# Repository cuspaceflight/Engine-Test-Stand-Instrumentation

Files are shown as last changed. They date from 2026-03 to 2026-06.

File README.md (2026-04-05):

# Cambridge University Space Flight Engine Test Stand

This repo contains documents for CUSF engine test stand. The electronics are split across 2 circuit boards:

**Servo + Solenoid Board**  Drives 2 solenoid valves (MPQ6610 half-bridge ICs) and up to 4 servos
**Instrumentation Board** Reads pressure transducers, thermocouples, and a load cell for thrust measurement

A laptop running ground-station software sends commands to the ESP32 on the servo board, and polls the Instrumentation Board to read sensor data

## Board Details

### Servo + Solenoid Board

This board contains the circuits for driving the servos and solenoids. Uses an ESP32 microcontroller (ESP32 S3 DevKit C1). The microcontroller is alos responsible for: 
 - Communication with laptop
 - Driving servos and solenoids
 - Inputs raw data from sensors and sends to laptop

#### Solenoid Section

Each of the solenoid channels uses an **MPS MPQ6610** half-bridge power driver. 

#### Servo Section

4 servos (FeeTech 180 Degrees Digital Servo 7.4V 35kg/cm FT5330M)
 - PWM signal from ESP32

### Instrumentation Board

- Load cell
- 8 Pressure sensors
- 4 thermocouples

## Repository Structure

```
cusf-engine_test_stand/
│
├── hardware/
│   ├── master-board/
│   │   ├── kicad/              # Schematic + PCB project
│   │
│   ├── servo-solenoid-board/
│   │   ├── kicad/
│   │
│   ├── instrumentation-board/
│   │   ├── kicad/
│   │
│   ├── Datasheets
│   │   ├── MPQ6610.pdf
│   │
│
├── Software/
│   ├── servo/
│   ├── solenoid/
│   ├── instrumentation/
│   ├──Laptop software (GUI + logging)
│
└── README.md

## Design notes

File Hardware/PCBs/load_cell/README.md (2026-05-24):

# CUSF Load Cell Interface Board

## Overview

Signal conditioning board for the PW16A load cell, providing excitation voltage, instrumentation amplification, low-pass filtering, and buffered voltage references for ADC reading.

---

## Connector

| Designator | Description |
|---|---|
| J1 | RS Pro M12 Connector Female, 8W-8C, 5m, PVC, Shield |

---

## Load Cell

| Parameter | Value |
|---|---|
| Model | PW16A |
| Sensitivity | 2 mV/V |
| Excitation Voltage | 10 V |
| Full-scale Output | 20 mV (0.02 V) |

---

## Power Section

### Voltage Regulation & References

| Designator | Part | Description | Package |
|---|---|---|---|
| U4 | L78L05 | 5V Positive Linear Regulator, 100mA, 30V Max Input | SOIC-8 |
| U2 | REF5010AD | 10V Precision Voltage Reference, 0.1% Accuracy, 10mA, Low Noise | SOIC-8 |
| U5 | REF3033 | 3.3V CMOS Voltage Reference, 50 ppm/°C Max, 50 µA | SOT-23 |

### Op-Amp Buffers

| Designator | Part | Description | Package | Purpose |
|---|---|---|---|---|
| U3 | OPA197xD | 36V Precision, Rail-to-Rail I/O, Low Offset Voltage Op-Amp | SOIC-8 | 10V reference buffer |
| U6 | OPA333xxD | 1.8V microPower, CMOS Zero-Drift Op-Amp | SOIC-8 | 3.3V reference buffer |

### Resistors

| Designator | Value | Package |
|---|---|---|
| R2 | 1 Ω | 0805 |
| R3 | 16.2 kΩ | 0805 |
| R4 | 1.8 kΩ | 0805 |

### Capacitors

| Designator | Value | Package |
|---|---|---|
| C3 | 100 nF | 0805 |
| C4 | 100 nF | 0805 |
| C5 | 100 nF | 0805 |
| C6 | 100 nF | 0805 |
| C7 | 10 µF | 0805 |
| C8 | 10 µF | 0805 |
| C9 | 10 µF | 0805 |
| C10 | 1 µF | 0805 |
| C11 | 100 nF | 0805 |
| C12 | 1 µF | 0805 |
| C13 | 100 nF | 0805 |

### Outputs

| Signal | Source | Description |
|---|---|---|
| VOUT_10V | REF5010AD + OPA197xD buffer | 10V excitation for load cell |
| VREF_0.33V | REF3033 + OPA333xxD buffer | 0.33V reference for ADC |

---

## Analogue Signal Section

### Instrumentation Amplifier

| Designator | Part | Description | Package |
|---|---|---|---|
| U1 | AD8422 | Single High Performance, Low Power, Rail-to-Rail Precision In-Amp | SOIC-8 |

| Parameter | Value |
|---|---|
| Gain (G) | 150 |
| Gain Resistor (RG) | 133 Ω |
| Formula | RG = 19.8 kΩ / (G − 1) |
| Supply Voltage | +15V (single-supply) |
| Output to ESP | 3.0 V |

### Gain Resistor

| Designator | Value | Package |
|---|---|---|
| RG | 133 Ω | 0805 |

### Low-Pass Filter

| Designator | Value | Package | Notes |
|---|---|---|---|
| R1 | 5.36 kΩ | 0805 | Series resistor |
| C1 | 10 nF | 0805 | Shunt capacitor |

| Parameter | Value |
|---|---|
| Cut-off Frequency | 2.97 kHz |
| Topology | RC low-pass filter |

### Decoupling Capacitor

| Designator | Value | Package |
|---|---|---|
| C2 | 0.1 µF | 0805 |

### Signals

| Signal | Direction | Description |
|---|---|---|
| LC_SIG+ | Input | Load cell differential signal (+) |
| LC_SIG- | Input | Load cell differential signal (−) |
| +15V_Analog | Input | 15V supply for AD8422 |
| V_REF | Input | 0.33V reference for AD8422 output offset |
| ADC_OUT_TO_MIC | Output | Filtered, amplified signal to microcontroller ADC |
| AGND | — | Analogue ground |

---

## Inter-Sheet Connections

| Main Sheet Label | Power Sheet | Analogue Signal Sheet | J1 (M12 Connector) |
|---|---|---|---|
| VIN_15V | Input | — | — |
| VOUT_10V | ← Output | — | — |
| VREF_0.33V | ← Output | → V_REF | — |
| +10V_EXC | — | — | Pins 1, 8 |
| LC_SIG+ | — | ← Input | Pin (signal) |
| LC_SIG- | — | ← Input | Pin (signal) |
| AGND | ✓ | ✓ | Ground pins |
| ADC_OUT_TO_MIC | — | → Output | — |

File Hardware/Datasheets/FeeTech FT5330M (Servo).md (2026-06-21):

# Servo Motor Specifications

### Environmental & Physical Specifications
* **Storage Temperature Range:** -30 ~ 80 °C
* **Operating Temperature Range:** -20 ~ 60 °C
* **Weight:** 67 ± 1 g
* **Case Material:** PA + Aluminum

### Mechanical Specifications
* **Gear Type:** Steel
* **Limit Angle:** No limit
* **Bearing Type:** Ball bearings
* **Horn Gear Spline:** 25T / 5.9 mm
* **Horn Type:** Plastic, POM

### Electrical Specifications
* **Motor Type:** Core Motor
* **Operating Voltage Range:** 6.0 V - 7.4 V
* **Idle Current (at stopped):** 6 mA @ 7.4 V
* **Running Current (at no load):** 180 mA @ 7.4 V
* **Stall Current:** 3.9 A @ 7.4 V

### Performance Specifications
* **No-load Speed:** 0.192 sec / 60° @ 7.4 V
* **Peak Stall Torque:** 35.5 kg·cm @ 7.4 V
* **Rated Torque:** 11.8 kg·cm @ 7.4 V

### Control & Signal Specifications
* **Command Signal:** Pulse Width Modulation (PWM)
* **Amplifier Type:** Digital comparator
* **Pulse Width Range:** 500 ~ 2500 μsec
* **Stop Position:** 1500 μsec
* **Running Degree:** 220° Continuous Rotation
* **Dead Band Width:** ≤ 4 μsec
* **Rotating Direction:** Counterclockwise (1500 - 2000 μsec)

### Pin Definition
* **Pin 1:** Signal
* **Pin 2:** Vcc
* **Pin 3:** GND

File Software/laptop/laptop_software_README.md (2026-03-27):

# Ground Station GUI — Technical Documentation

## What this software does

This is the laptop application for the CUSF static fire test stand. It connects to the ESP32-S3 microcontroller on the actuation board over a USB cable and lets the operator control valves and monitor sensors during an engine test firing.

The software is three Python files totalling about 500 lines. Each file has one job:

| File | Job | Analogy |
|---|-----|---|
| `protocol.py` | Defines the language the GUI and ESP32 speak | A dictionary / phrasebook |
| `serial_comms.py` | Manages the USB cable connection | A telephone line |
| `main.py` | The window you see and click on | The control room |

---

## How it connects to the hardware

```
 ┌─────────────┐    USB-C cable    ┌───────────────────────────┐
 │   LAPTOP    │◄─────────────────►│   ACTUATION BOARD         │
 │             │   (virtual serial │                           │
 │  main.py    │    port, 115200   │   ESP32-S3-DevKitC-1     │
 │  (this GUI) │    baud)          │     │                     │
 │             │                   │     ├── GPIO → MPQ6610 #1 ──► Solenoid 1
 └─────────────┘                   │     ├── GPIO → MPQ6610 #2 ──► Solenoid 2
                                   │     ├── PWM  → Servo 1 (FT5330M)
                                   │     ├── PWM  → Servo 2 (FT5330M)
                                   │     ├── PWM  → Servo 3 (FT5330M)
                                   │     ├── PWM  → Servo 4 (FT5330M)
                                   │     └── Bus  → Instrumentation Board
                                   └───────────────────────────┘
```

The ESP32-S3 has **native USB** built into the chip (on GPIO19 and GPIO20). When you plug a USB-C cable into the DevKitC-1, the laptop sees it as a virtual serial port — `COM3` on Windows or `/dev/ttyACM0` on Linux. No special driver is needed.

Serial communication is just sending text back and forth, one line at a time, at 115200 bits per second. It is the same protocol the Arduino Serial Monitor uses.

---

## File 1: protocol.py

### Purpose

This file is a contract between the GUI and the ESP32 firmware. It defines exactly what strings are sent in each direction and provides Python classes to construct and parse them.

Your teammate writing the ESP32 firmware needs to agree on this file. If both sides follow the same protocol, they will work together even though they are written independently.

### How the protocol works

Every message is a line of ASCII text ending with a newline character (`\n`). We use text rather than binary because:

1. You can type commands into any serial terminal for debugging
2. You can read the log files with a text editor
3. Parsing is simple string splitting

### Commands (GUI → ESP32)

When you click a button in the GUI, it creates a Command object and sends it over serial. Here is the complete chain for turning on solenoid 1:

```
User clicks "SOL 1" button
        │
        ▼
GUI creates: SolenoidCommand(channel=1, on=True)
        │
        ▼
SolenoidCommand.to_str() returns: "SOL1:ON\n"
        │
        ▼
SolenoidCommand.to_bytes() encodes to: b"SOL1:ON\n"
        │
        ▼
pyserial sends these bytes over USB
        │
        ▼
ESP32 receives "SOL1:ON\n", sets MPQ6610 #1 EN=HIGH, IN=HIGH
        │
        ▼
MPQ6610 high-side MOSFET turns on → 24V flows through solenoid
        │
        ▼
Solenoid energises → valve opens
```

### Messages (ESP32 → GUI)

The ESP32 periodically sends sensor readings and fault status without being asked. The `parse_response()` function converts each line into a typed Python object:

```
ESP32 sends: "FAULT:1:0\n"
        │
        ▼
parse_response("FAULT:1:0") splits on ":"
        │
        ▼
Returns: FaultMessage(channel=1, ok=False)
        │
        ▼
GUI checks isinstance(msg, FaultMessage)
        │
        ▼
Updates the nFAULT indicator for channel 1 to red
```

### The class hierarchy

```
Command (base class — "something we send")
├── SolenoidCommand    channel, on        → "SOL1:ON\n"
├── ServoCommand       channel, pulse_us  → "SRV2:1500\n"
└── StatusCommand      (no data)          → "STATUS\n"

Message (base class — "something we receive")
├── FaultMessage       channel, ok        ← "FAULT:1:0"
├── SensorMessage      name, value        ← "SENSOR:PRESS1:3.45"
├── AckMessage         (no data)          ← "OK"
├── ErrorMessage       message            ← "ERROR:Invalid command"
├── StatusMessage      raw                ← "STATUS:SOL1:ON:..."
└── UnknownMessage     raw                ← anything else
```

### What @dataclass does

The `@dataclass` decorator is a shortcut. It automatically generates the `__init__` method and a readable `__repr__`. These two are equivalent:

```python
# Without @dataclass (verbose)
class FaultMessage(Message):
    def __init__(self, channel: int, ok: bool):
        self.channel = channel
        self.ok = ok
    def __repr__(self):
        return f"FaultMessage(channel={self.channel}, ok={self.ok})"

# With @dataclass (compact — Python generates the above for you)
@dataclass
class FaultMessage(Message):
    channel: int
    ok: bool
```

### What `__post_init__` does (in ServoCommand)

`@dataclass` generates `__init__` for you, so you cannot write your own. But sometimes you need to run extra logic after the object is created (like clamping the servo pulse range to 500–2500). `__post_init__` is called automatically right after `__init__` finishes:

```python
cmd = ServoCommand(channel=1, pulse_us=9999)
# 1. @dataclass __init__ runs:  self.channel=1, self.pulse_us=9999
# 2. __post_init__ runs:        self.pulse_us = max(500, min(2500, 9999)) → 2500
# Result: cmd.pulse_us == 2500
```

---

## File 2: serial_comms.py

### Purpose

Manages the USB serial connection to the ESP32. Handles port discovery, connecting, disconnecting, sending commands, and reading incoming data on a background thread.

### Why a background thread?

Serial reading is **blocking** — `ser.readline()` waits until a complete line arrives. If you did this on the main thread (the one running the GUI), the entire window would freeze:

```
Without background thread:
    User clicks button → GUI tries to read serial → waits...
    → waits... → waits... → meanwhile GUI is frozen, user
    can't click anything, window says "Not Responding"
```

With a background thread, reading happens independently:

```
Main thread:              Background thread:
    GUI draws widgets         Checks for serial data
    User clicks buttons       Reads a line
    Sliders move              Parses it
    Labels update             Calls the callback
         ▲                          │
         └──── self.after() ────────┘
              (safely passes data between threads)
```

### The callback pattern explained

The serial module doesn't know anything about the GUI. It doesn't import `main.py`. Instead, the GUI gives serial_comms a function to call when data arrives. This is called the **callback pattern**.

Here is the simplest possible example of the pattern:

```python
# === The serial module's perspective ===
class SerialConnection:
    def __init__(self):
        self._on_receive = None       # No callback yet

    def set_callback(self, func):
        self._on_receive = func       # Store the function

    def _read_loop(self):
        data = "FAULT:1:0"            # Pretend we read this
        msg = parse_response(data)    # Turn it into a FaultMessage
        self._on_receive(msg)         # Call whatever function was stored

# === The GUI's perspective ===
class MyGUI:
    def __init__(self):
        self.serial = SerialConnection()

        # "When you get data, call my handle_it method"
        self.serial.set_callback(self.handle_it)

    def handle_it(self, msg):
        print(f"GUI got: {msg}")
```

When `_read_loop` runs `self._on_receive(msg)`, it is calling `self.handle_it(msg)` on the GUI — because that is the function that was stored by `set_callback`.

Think of it like a restaurant:
1. You give the waiter your phone number (set_callback)
2. The waiter writes it down (_on_receive = func)
3. When your table is ready, the waiter calls you (_on_receive(msg))
4. You pick up the phone and act on it (handle_it runs)

### Thread safety and self.after()

There is one complication: the callback runs on the **background thread**, but GUI widgets (buttons, labels, etc.) can only be updated from the **main thread**. If you try to change a label's text from the background thread, the application crashes.

The solution is `self.after(0, function, args)`, which means: "schedule this function to run on the main thread as soon as possible."

```python
def on_serial_receive(self, msg):
    # This runs on the BACKGROUND thread (called by _read_loop)
    # Do NOT touch any GUI widgets here!

    # Instead, schedule _handle_message to run on the main thread:
    self.after(0, self._handle_message, msg)

def _handle_message(self, msg):
    # This runs on the MAIN thread (scheduled by self.after)
    # Safe to update GUI widgets here:
    self.fault_labels[1].configure(text="● FAULT!", text_color="red")
```

### The read loop in detail

```python
def _read_loop(self):
    while self._running:                    # Loop until disconnect() sets this False
        if self.ser.in_waiting:             # Are there bytes in the USB buffer?
            raw = self.ser.readline()       #   YES: read one line (blocks until \n)
            text = raw.decode("utf-8")      #   Convert bytes to string
            msg = parse_response(text)      #   "FAULT:1:0" → FaultMessage(1, False)
            self._on_receive(msg)           #   Call the GUI's callback
        else:
            time.sleep(0.01)                #   NO: wait 10ms, check again
```

The `in_waiting` check is important. Without it, `readline()` would block for up to 100ms (the timeout we set) every iteration, even when there is no data. By checking first, we only call readline when we know data is there — this keeps the loop responsive.

---

## File 3: main.py

### Purpose

The GUI window — everything the operator sees and interacts with. Built with `customtkinter`, which is a modern-looking wrapper around Python's built-in `tkinter` GUI library.

### Window layout

```
┌──────────────────────────────────────────────────┐
│  [Port: COM3 ▼]  [Refresh]  [Connect]  ● Green  │  ← Connection bar
├────────────────────────┬─────────────────────────┤
│  Solenoids             │  Sensors                │
│  ┌─────────────┬─────┐ │  Pressure 1:  3.4 bar   │
│  │ SOL 1: OFF  │ ● OK│ │  Pressure 2:  2.1 bar   │
│  │ SOL 2: OFF  │ ● OK│ │  Temperature: 25.3 °C   │
│  └─────────────┴─────┘ │  Thrust:      142.7 N   │
│                         │                         │
│  Servos                 │  Log                    │
│  [All Closed] [Centre]  │  [09:41:23] Connected   │
│  Servo 1: ───●─── 1500 │  [09:41:24] SOL 1 → ON  │
│  Servo 2: ───●─── 1500 │  [09:41:25] SENSOR ...  │
│  Servo 3: ───●─── 1500 │  [09:41:25] FAULT on 1! │
│  Servo 4: ───●─── 1500 │  [09:41:26] SENSOR ...  │
└────────────────────────┴─────────────────────────┘
```

### How each GUI element maps to hardware

**Solenoid buttons → MPQ6610 → Solenoid valves**

When you click "SOL 1", the GUI sends `SOL1:ON\n` over USB. The ESP32 firmware receives this, sets GPIO4=HIGH (EN) and GPIO5=HIGH (IN). Inside the MPQ6610, this turns on the high-side MOSFET, connecting the solenoid coil to the 24V supply. Current flows through the coil, creating a magnetic field that pulls the plunger and opens the valve.

When you click again (OFF), the GUI sends `SOL1:OFF\n`. The ESP32 sets GPIO4=LOW (EN). The MPQ6610 turns off both MOSFETs (Hi-Z state). Current stops flowing, the solenoid's spring pushes the plunger back, and the valve closes.

**nFAULT indicators → MPQ6610 nFAULT pin → ESP32 GPIO**

The MPQ6610 has a built-in fault detection pin (nFAULT). It is normally HIGH (pulled up by a 10kΩ resistor to 3.3V). If the MPQ6610 detects a problem — solenoid drawing too much current (>3A), chip overheating (>165°C), solenoid disconnected, or supply voltage too low (<4.1V) — it pulls nFAULT LOW.

The ESP32 reads this pin (GPIO8 for channel 1, GPIO9 for channel 2) and sends `FAULT:1:0\n` or `FAULT:1:1\n` to the GUI. The GUI updates the indicator dot: green for OK, red for FAULT.

**Servo sliders → ESP32 LEDC PWM → FT5330M servos → Ball valves**

When you drag a slider, the GUI sends (for example) `SRV1:1800\n`. The ESP32 firmware updates its LEDC peripheral to output a 50Hz PWM signal with an 1800µs pulse width on the corresponding GPIO pin (GPIO10–13). The FT5330M servo's internal controller reads this pulse and moves the output shaft to the corresponding angle. The servo horn is mechanically linked to a ball valve, rotating it to control flow.

The FT5330M accepts 500–2500µs pulses (0–180°). The slider is clamped to this range.

**Sensor readings → Instrumentation board → ESP32 → GUI**

The ESP32 periodically polls the instrumentation board (your teammate's board) over the inter-board bus. It reads pressure transducers, thermocouples, and the load cell, then sends `SENSOR:PRESS1:3.45\n` to the GUI. The GUI updates the number on screen. These readings are also logged to a CSV file.

The solenoid control logic on the ESP32 uses these sensor readings to make decisions — for example, opening the fuel valve when tank pressure reaches a target value.

### The main thread vs background thread

This is the most important architectural concept in the code. Python GUI applications (tkinter, Qt, etc.) have a strict rule: **only the main thread can touch GUI widgets**. If a background thread tries to change a label's text, the application crashes or behaves unpredictably.

But we need a background thread to read serial data continuously without freezing the GUI. The solution:

```
MAIN THREAD                         BACKGROUND THREAD
(runs the GUI)                      (reads serial data)
     │                                    │
     │  app.mainloop()                    │  _read_loop()
     │  ├── draws widgets                 │  ├── ser.readline()
     │  ├── handles button clicks         │  ├── parse_response()
     │  ├── runs self.after() tasks ◄─────│──├── self._on_receive(msg)
     │  │         │                       │  │     calls on_serial_receive()
     │  │         ▼                       │  │     which calls self.after()
     │  │   _handle_message(msg)          │  │
     │  │   ├── update fault label        │  └── sleep, loop again
     │  │   ├── update sensor value       │
     │  │   └── write to log              │
     │  └── loop                          │
```

`self.after(0, func, args)` is the bridge: it says "next time the main thread's event loop checks, please run this function." It is safe because the function actually executes on the main thread — the background thread only schedules it.

### Logging

Every event is logged to two places:

1. **GUI log panel** — visible on screen, scrolls automatically, timestamped
2. **CSV file** — in the `logs/` folder, named by date/time, can be opened in Excel or Python for post-test analysis

The CSV format is: `timestamp,type,data`

```csv
2026-03-27T14:23:01.123,SENSOR PRESS1: 3.45
2026-03-27T14:23:01.124,SENSOR TEMP1: 25.3
2026-03-27T14:23:01.125,FAULT on solenoid 1!
2026-03-27T14:23:02.001,SOL 1 → OFF
```

---

## How to test without the ESP32

The `add_mock_data()` function at the bottom of `main.py` simulates the ESP32 sending data. Uncomment it in `__main__`:

```python
if __name__ == "__main__":
    app = TestStandGUI()
    add_mock_data(app)      # ← uncomment this line
    app.mainloop()
```

This calls `_handle_message()` directly every 200ms with fake sensor readings and occasional fault events. The GUI behaves exactly as it would with a real ESP32, except no USB cable is needed. Use this to develop and demo the GUI before the hardware is ready.

---

## Dependencies

```bash
pip install pyserial customtkinter matplotlib
```

| Library | Version | What it does |
|---|---|---|
| `pyserial` | 3.5+ | Talks to the ESP32 over the USB virtual serial port |
| `customtkinter` | 5.0+ | Modern-looking GUI widgets (buttons, sliders, labels) |
| `matplotlib` | 3.7+ | For live plots (to be added in a future version) |
| `tkinter` | (built-in) | The underlying GUI framework. Ships with Python. |
| `threading` | (built-in) | Background thread for serial reading |
| `dataclasses` | (built-in) | The `@dataclass` decorator for protocol classes |

---

## File structure

```
ground-station/
├── main.py              # GUI window — run this
├── serial_comms.py      # USB serial connection handler
├── protocol.py          # Protocol definition (commands + messages)
├── logs/                # Auto-created, contains CSV log files
│   └── log_20260327_142301.csv
└── README.md            # This file
```

---

## Glossary

| Term | Meaning |
|---|---|
| **Baud rate** | Communication speed in bits per second. 115200 is standard for ESP32. Both sides must agree on the same rate. |
| **Callback** | A function you pass to another module for it to call later. Like leaving your phone number at a restaurant. |
| **Daemon thread** | A background thread that automatically terminates when the main program exits. Set with `daemon=True`. |
| **LEDC** | LED Control — the ESP32's hardware PWM peripheral. Despite the name, it is used for servo control too. Generates precise pulse timing without CPU involvement. |
| **Main thread** | The thread that runs the GUI event loop (`mainloop()`). Only this thread may update widget properties. |
| **MPQ6610** | The half-bridge solenoid driver IC. Receives EN and IN signals from ESP32 GPIOs. Drives 24V through the solenoid coil. Reports faults on the nFAULT pin. |
| **nFAULT** | Active-low fault indicator on the MPQ6610. "n" prefix means the signal is active when LOW. Pulled HIGH by a 10kΩ resistor when everything is fine. |
| **PWM** | Pulse Width Modulation. A digital signal that switches between high and low at a fixed frequency. The ratio of high time to total period (the duty cycle) encodes information — for servos, it encodes the desired angle. |
| **pyserial** | Python library for serial port communication. Provides the `serial.Serial` class that reads/writes bytes over USB. |
| **self.after()** | A tkinter method that schedules a function to run on the main thread after a delay (0ms = as soon as possible). Used to safely pass data from a background thread to the GUI. |
| **Virtual serial port** | When the ESP32-S3's native USB is connected, the operating system creates a software serial port (COM3, /dev/ttyACM0) that programs can read/write as if it were a physical RS-232 port. |

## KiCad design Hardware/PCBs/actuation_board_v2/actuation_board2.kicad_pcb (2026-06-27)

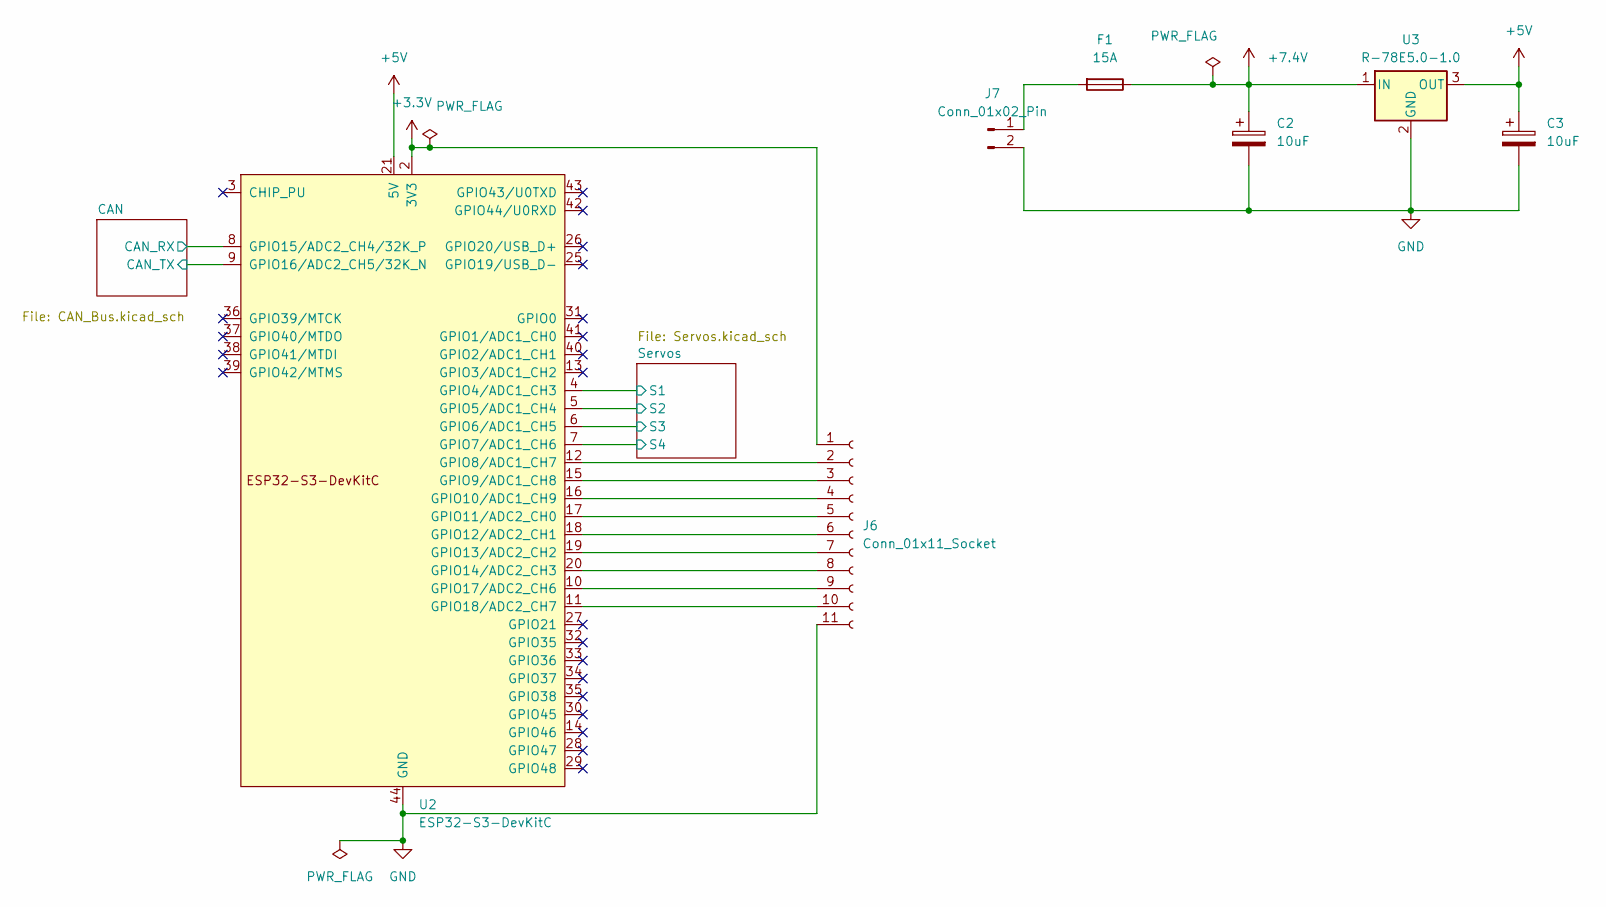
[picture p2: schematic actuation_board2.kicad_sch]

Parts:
C2, C3: 10uF; C_0603_1608Metric_Pad1.08x0.95mm_HandSolder
F1: 15A; Fuse_1206_3216Metric_Pad1.42x1.75mm_HandSolder
J6: Conn_01x11_Socket; PinSocket_1x11_P2.54mm_Vertical
J7: Conn_01x02_Pin; AMASS_XT60PW-M_1x02_P7.20mm_Horizontal
U2: ESP32-S3-DevKitC
U3: R-78E5.0-1.0; Converter_DCDC_RECOM_R-78E-0.5_THT

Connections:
+3.3V: J6.1, U2.1 (3V3), U2.2 (3V3); also elsewhere on the board
+5V: C3.1, U2.21 (5V), U3.3 (OUT)
+7.4V: C2.1, F1.1, U3.1 (IN); also elsewhere on the board
/CAN/CAN_RX: U2.8 (GPIO15/ADC2_CH4/32K_P); also elsewhere on the board
/CAN/CAN_TX: U2.9 (GPIO16/ADC2_CH5/32K_N); also elsewhere on the board
/Servos/S1: U2.4 (GPIO4/ADC1_CH3); also elsewhere on the board
/Servos/S2: U2.5 (GPIO5/ADC1_CH4); also elsewhere on the board
/Servos/S3: U2.6 (GPIO6/ADC1_CH5); also elsewhere on the board
/Servos/S4: U2.7 (GPIO7/ADC1_CH6); also elsewhere on the board
GND: C2.2, C3.2, J6.11, J7.2, U2.22 (GND), U2.23 (GND), U2.24 (GND), U2.44 (GND), U3.2 (GND); also elsewhere on the board
unnamed: J6.2, U2.12 (GPIO8/ADC1_CH7)
unnamed: J6.3, U2.15 (GPIO9/ADC1_CH8)
unnamed: J6.4, U2.16 (GPIO10/ADC1_CH9)
unnamed: J6.5, U2.17 (GPIO11/ADC2_CH0)
unnamed: J6.6, U2.18 (GPIO12/ADC2_CH1)
unnamed: J6.7, U2.19 (GPIO13/ADC2_CH2)
unnamed: J6.8, U2.20 (GPIO14/ADC2_CH3)
unnamed: J6.9, U2.10 (GPIO17/ADC2_CH6)
unnamed: J6.10, U2.11 (GPIO18/ADC2_CH7)
unnamed: F1.2, J7.1

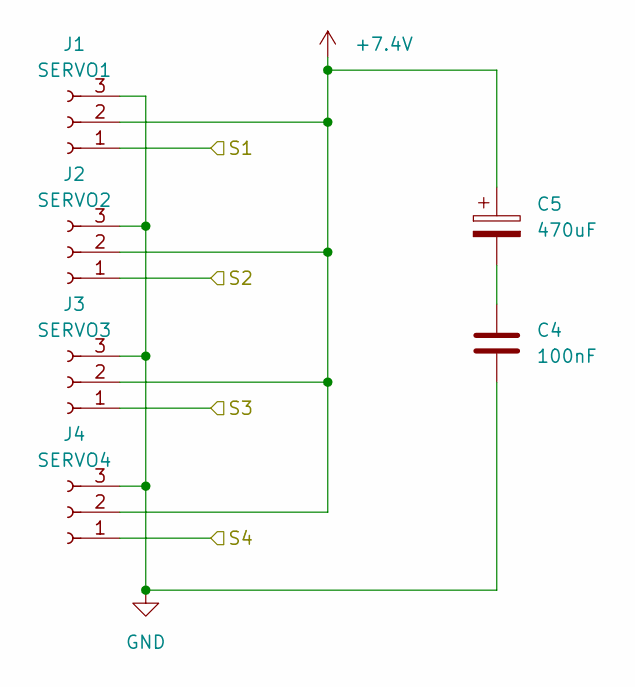
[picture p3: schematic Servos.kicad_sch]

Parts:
C4: 100nF; C_0603_1608Metric_Pad1.08x0.95mm_HandSolder
C5: 470uF; CP_Elec_8x10.5
J1: SERVO1; PinHeader_1x03_P2.54mm_Vertical
J2: SERVO2; PinHeader_1x03_P2.54mm_Vertical
J3: SERVO3; PinHeader_1x03_P2.54mm_Vertical
J4: SERVO4; PinHeader_1x03_P2.54mm_Vertical

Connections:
+7.4V: C5.1, J1.2, J2.2, J3.2, J4.2; also elsewhere on the board
/Servos/S1: J1.1; also elsewhere on the board
/Servos/S2: J2.1; also elsewhere on the board
/Servos/S3: J3.1; also elsewhere on the board
/Servos/S4: J4.1; also elsewhere on the board
GND: C4.2, J1.3, J2.3, J3.3, J4.3; also elsewhere on the board
unnamed: C4.1, C5.2

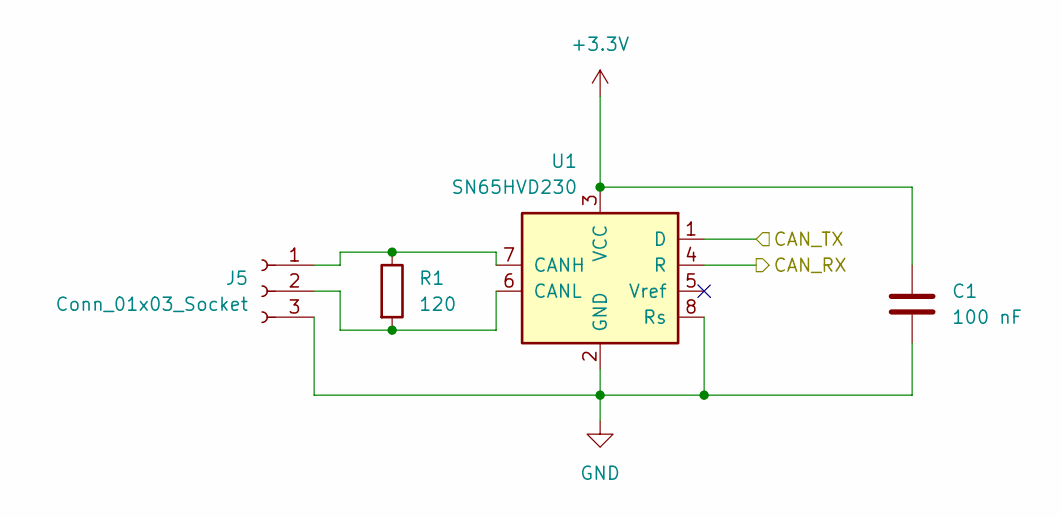
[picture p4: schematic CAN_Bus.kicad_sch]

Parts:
C1: 100 nF; C_0603_1608Metric_Pad1.08x0.95mm_HandSolder
J5: Conn_01x03_Socket; PinSocket_1x03_P2.54mm_Vertical
R1: 120; R_0805_2012Metric_Pad1.20x1.40mm_HandSolder
U1: SN65HVD230; SOIC-8_3.9x4.9mm_P1.27mm

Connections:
+3.3V: C1.1, U1.3 (VCC); also elsewhere on the board
/CAN/CAN_RX: U1.4 (R); also elsewhere on the board
/CAN/CAN_TX: U1.1 (D); also elsewhere on the board
GND: C1.2, J5.3, U1.2 (GND), U1.8 (Rs); also elsewhere on the board
unnamed: J5.1, R1.1, U1.7 (CANH)
unnamed: J5.2, R1.2, U1.6 (CANL)

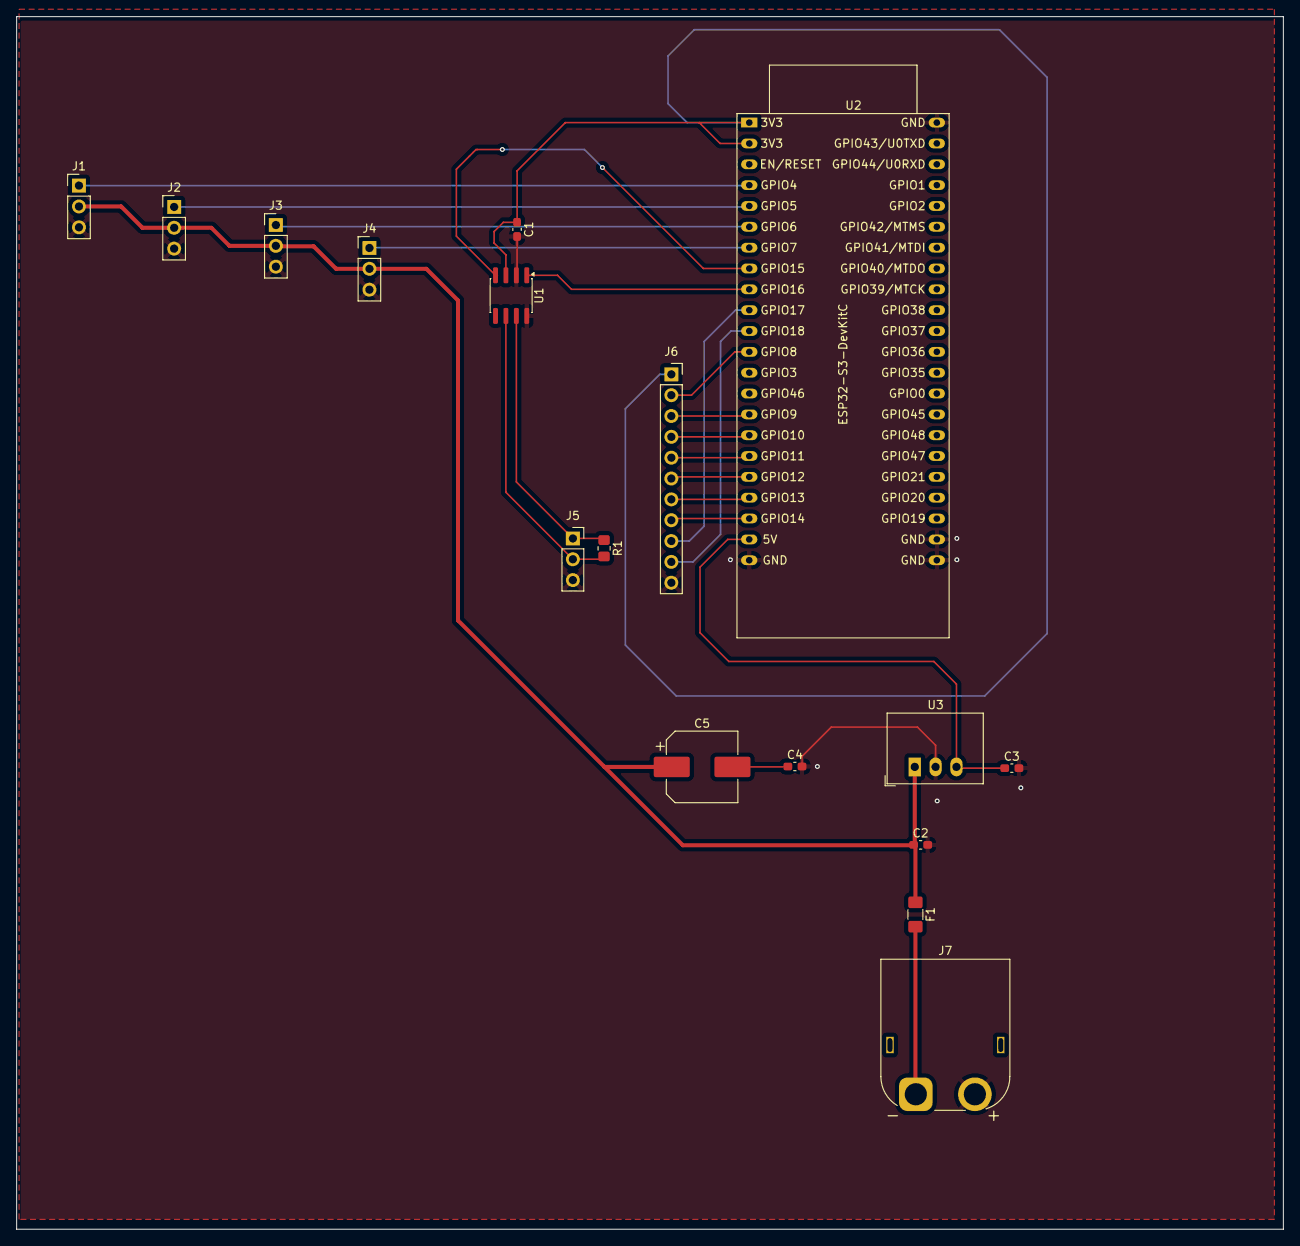
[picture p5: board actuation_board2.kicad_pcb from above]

Board: 2 copper layers, 154.4 x 147.8 mm, 17 parts (0 on the bottom side), 23 nets.

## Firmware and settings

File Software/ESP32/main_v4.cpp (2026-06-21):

/*
 * main_v3.cpp — CUSF Actuation Board v2 Firmware  (v3.1)
 *
 * Runs on: ESP32-S3-DevKitC-1
 * Talks to:
 *   Laptop GUI      — native USB serial, ASCII protocol
 *   Instr. board    — CAN bus at 500 kbps via SN65HVD230 transceiver
 *
 * ─────────────────────────────────────────────────────────────────────────────
 * v3.1 SAFETY CHANGES vs the version you uploaded (all reviewed below):
 *   [S1] Operator-link fail-safe. If the firmware does not hear from the GUI
 *        within GUI_LINK_TIMEOUT_MS, it drives every servo to its configured
 *        SAFE position and LATCHES a fail-safe state. Servo move commands are
 *        rejected until an explicit RESET re-arms it. This closes the single
 *        biggest gap: previously a crashed/yanked laptop left valves frozen
 *        wherever they were last commanded. REQUIRES the v3.1 GUI (it PINGs).
 *   [S2] Atomic ABORT / RESET commands. ABORT = one frame → all servos safe +
 *        latch. RESET = re-arm. Replaces four separate SRV:500 sends.
 *   [S3] CAN bus-off detection + recovery. The previous comment claimed TWAI
 *        recovers automatically — it does NOT. ESP-IDF requires an explicit
 *        twai_initiate_recovery() + twai_start(). Without this the board goes
 *        permanently CAN-silent after any bus-off (e.g. a transient short or
 *        EMI burst near the stand). Now handled.
 *   [S4] Larger CAN RX queue (32) so loop jitter does not drop sensor frames.
 *   [S5] Optional hardware task watchdog: a hung loop now resets the chip,
 *        and because setup() drives servos safe, a reset fails the stand safe.
 *
 * The servo/LEDC code, the CAN decode path, and the USB protocol are otherwise
 * UNCHANGED. See CODE_OVERVIEW.md for the full change list and rationale.
 *
 * ⚠ VERSION NOTE — READ BEFORE BUILDING:
 *   This firmware targets Arduino-ESP32 core 2.0.x:
 *     - LEDC uses ledcSetup() / ledcAttachPin() / ledcWrite(channel, duty)
 *     - esp_task_wdt_init(timeout_s, panic) takes two scalar args
 *   Core 3.0.x REMOVED that LEDC API (use ledcAttach()/ledcWrite(pin,duty))
 *   and CHANGED esp_task_wdt_init() to take a config struct. If your build
 *   fails to compile, you are almost certainly on core 3.x — either pin the
 *   platform to a 2.0.x-providing release in platformio.ini (recommended for
 *   reproducibility) or migrate those two APIs. Confirm your installed core
 *   from the build log line: framework-arduinoespressif32 @ x.y.z
 *
 * Build with PlatformIO:
 *   pio run -e esp32s3_v3              (compile  ← FIRST validation gate)
 *   pio run -e esp32s3_v3 -t upload    (flash)
 *   pio run -e esp32s3_v3 -t monitor   (open serial monitor)
 */

#include <Arduino.h>
#include <string.h>
#include "driver/twai.h"     // ESP-IDF CAN (TWAI) driver — bundled, no extra library

// [S5] Hardware task watchdog. Set to 0 if it will not compile on your core
//      version (the API differs on core 3.x — see VERSION NOTE above).
//      MUST be considered part of the safety case for any live test.
#define ENABLE_TASK_WDT  1
#if ENABLE_TASK_WDT
  #include "esp_task_wdt.h"
#endif

// [S1] Operator-link fail-safe. MUST be 1 for any test involving propellant or
//      pressurisation. Set to 0 ONLY for isolated bench servo testing with a
//      plain serial terminal that cannot send PING (otherwise the board will
//      correctly latch safe ~1.5 s after the last command).
#define ENABLE_LINK_FAILSAFE  1

#include "pins_v3.h"
#include "calibration.h"


// ═══════════════════════════════════════════════════════════════
// STATE
// ═══════════════════════════════════════════════════════════════

// Current servo positions in microseconds. Index 0 is unused —
// servos are 1-indexed throughout to match the J1–J4 labelling on the PCB.
int servo_pulse[5] = {0, SERVO_MIN_US, SERVO_MIN_US, SERVO_MIN_US, SERVO_MIN_US};

// ════════════════════════════════════════════════════════════════════════════
//  [S1/S2] SAFE STATE TABLE — SAFETY CRITICAL — REVIEW PER CHANNEL
// ════════════════════════════════════════════════════════════════════════════
//  The "safe" position of a valve is NOT generic. It is defined by the
//  plumbing P&ID:
//      - A main FUEL or OXIDISER valve is safe when CLOSED  (500 µs here).
//      - A VENT valve is safe when OPEN                     (2500 µs here).
//  A single "all closed" default is therefore an ASSUMPTION. This table is what
//  every servo is driven to on boot, on operator-link loss, and on ABORT.
//  The defaults assume all four channels are normally-closed valves. CONFIRM
//  EACH ENTRY against the actual plumbing before any pressurised test.
//
//  NOTE: the GUI's ABORT optimistically shows "all closed". If you change any
//  entry below to a non-closed safe state, update the GUI display assumption
//  to match (see CODE_OVERVIEW.md).
// ════════════════════════════════════════════════════════════════════════════
const int SERVO_SAFE_US[5] = {
    0,            // [0] unused
    SERVO_MIN_US, // CH1 — TODO confirm against P&ID
    SERVO_MIN_US, // CH2 — TODO confirm against P&ID
    SERVO_MIN_US, // CH3 — TODO confirm against P&ID
    SERVO_MIN_US, // CH4 — TODO confirm against P&ID
};

// ── CAN health ──────────────────────────────────────────────────────────────
// Start in the faulted state. can_fault is cleared when the first heartbeat
// arrives from the instrumentation board and set again if heartbeats stop.
bool can_fault = true;
unsigned long last_instr_hb_ms = 0;  // millis() when last 0x010 frame arrived

// How long without an instrumentation heartbeat before declaring a fault.
const unsigned long CAN_WATCHDOG_MS = 3000;

// ── [S1] Operator-link (USB/GUI) watchdog + latched fail-safe ────────────────
// last_gui_cmd_ms advances on EVERY line received from the GUI (any host line
// means a host is connected and talking). The v3.1 GUI also sends PING ~2 Hz so
// the link stays alive even when the operator is not clicking. If the gap
// exceeds GUI_LINK_TIMEOUT_MS the operator link is presumed lost.
unsigned long last_gui_cmd_ms = 0;
const unsigned long GUI_LINK_TIMEOUT_MS = 1500;   // ~3 missed 500 ms pings

// link_failsafe latches TRUE on boot, on ABORT, and on link loss. While true,
// servo MOVE commands are rejected. Cleared only by an explicit RESET while the
// link is alive — we do NOT auto-resume actuation after a dropout, because for
// propellant valves silently re-opening on link recovery is the worse hazard.
bool link_failsafe = true;

// Serial input buffer — accumulates characters until a newline arrives
String serial_buffer = "";

// ── Periodic task timers ────────────────────────────────────────────────────
unsigned long last_can_health_report_ms = 0;
const unsigned long CAN_HEALTH_REPORT_MS = 200;  // Keep GUI watchdog satisfied

unsigned long last_heartbeat_send_ms = 0;
const unsigned long HEARTBEAT_SEND_MS = 1000;    // Send our 0x020 once per second

// Firmware version embedded in the CAN heartbeat payload
const uint8_t FW_VERSION_MAJOR = 3;
const uint8_t FW_VERSION_MINOR = 1;


// Forward declarations for helpers defined lower down
void emit_state();
void enter_failsafe(const char *reason);


// ═══════════════════════════════════════════════════════════════
// SERVO FUNCTIONS  (unchanged from your v3 — LEDC core 2.x API)
// ═══════════════════════════════════════════════════════════════

/*
 * Convert a pulse width in microseconds to a LEDC duty value.
 *   At 50 Hz, one full period is 20 000 µs. With 14-bit resolution the duty
 *   range is 0–16 383 counts, so 1 µs maps to 16 383 / 20 000 ≈ 0.8192 counts.
 */
uint32_t microseconds_to_duty(int us) {
    uint32_t period_us = 1000000 / SERVO_FREQ_HZ;         // 20 000 µs at 50 Hz
    uint32_t max_duty  = (1u << SERVO_RESOLUTION) - 1;    // 16 383 at 14-bit
    return (uint32_t)((float)us / (float)period_us * (float)max_duty);
}

/*
 * Set servo [channel] (1–4) to [pulse_us]. pulse_us must be one of the three
 * GUI presets (500 / 1500 / 2500). LEDC channel index = servo channel − 1.
 */
void set_servo(int channel, int pulse_us) {
    if (channel < 1 || channel > 4) return;
    if (pulse_us != SERVO_MIN_US && pulse_us != SERVO_MID_US && pulse_us != SERVO_MAX_US) return;

    servo_pulse[channel] = pulse_us;
    ledcWrite(channel - 1, microseconds_to_duty(pulse_us));
}

/*
 * [S2] Drive every servo to its configured SAFE position (SERVO_SAFE_US).
 * Used by enter_failsafe(). Writes the LEDC duty directly so it works even
 * when the safe position is not one of the three presets set_servo() allows.
 */
void drive_all_servos_safe() {
    for (int ch = 1; ch <= 4; ch++) {
        servo_pulse[ch] = SERVO_SAFE_US[ch];
        ledcWrite(ch - 1, microseconds_to_duty(SERVO_SAFE_US[ch]));
    }
}


// ═══════════════════════════════════════════════════════════════
// [S1/S2] FAIL-SAFE STATE MACHINE
// ═══════════════════════════════════════════════════════════════

/*
 * Emit the current arm/fail-safe state to the GUI. Sent on every transition
 * and once per second (so a GUI connecting mid-stream learns the state). Uses
 * a dedicated STATE: prefix rather than ERROR:/FAULT: so it never disturbs the
 * GUI's OK/ERROR acknowledgement bookkeeping.
 */
void emit_state() {
    if (link_failsafe) {
        Serial.println("STATE:FAILSAFE:active");
    } else {
        Serial.println("STATE:ARMED");
    }
}

/*
 * Enter the latched fail-safe state: drive all servos safe, latch, notify.
 * Idempotent — calling it while already latched just re-drives the safe state.
 */
void enter_failsafe(const char *reason) {
    drive_all_servos_safe();
    bool was_armed = !link_failsafe;
    link_failsafe = true;
    if (was_armed) {
        Serial.print("WARNING:FAILSAFE entered (");
        Serial.print(reason);
        Serial.println(") — servos driven safe, RESET required to re-arm");
    }
    Serial.print("STATE:FAILSAFE:");
    Serial.println(reason);
}

/*
 * Re-arm (clear the latch). Only honoured while the operator link is alive,
 * which by construction it is whenever a RESET command has just been received.
 */
void arm_system() {
    link_failsafe = false;
    Serial.println("STATE:ARMED");
    Serial.println("INFO:System armed — servo commands accepted");
}


// ═══════════════════════════════════════════════════════════════
// CAN BUS FUNCTIONS
// ═══════════════════════════════════════════════════════════════

/*
 * Decode a 4× int16 little-endian CAN payload and emit SENSOR: lines.
 * Used for pressure (0x100/0x101) and thermocouple (0x102) frames.
 * value = raw * scale[ch] + offset[ch]; defaults pass raw counts through.
 */
void emit_four_int16(const twai_message_t &msg,
                     const char *sensor_prefix,
                     int first_channel,
                     const float *scale,
                     const float *offset) {
    for (int i = 0; i < 4; i++) {
        int16_t raw;
        // memcpy avoids UB from reading a possibly-unaligned int16 from bytes.
        memcpy(&raw, &msg.data[i * 2], sizeof(int16_t));

        int ch = first_channel + i;
        float value = (float)raw * scale[ch] + offset[ch];

        Serial.print("SENSOR:");
        Serial.print(sensor_prefix);
        Serial.print(ch);
        Serial.print(":");
        Serial.println(value, 2);
    }
}

/*
 * Decode and forward one CAN frame to the GUI over USB serial.
 *   0x010  Instrumentation heartbeat — reset watchdog, clear fault if set
 *   0x100  Pressure channels 1–4
 *   0x101  Pressure channels 5–8
 *   0x102  Thermocouple channels 1–4
 *   0x103  Load cell (int32 reading + status byte)
 *   other  Ignored (includes our own 0x020 echoed on RX)
 */
void handle_can_frame(const twai_message_t &msg) {
    switch (msg.identifier) {

        // ── Instrumentation board heartbeat ──────────────────────────────
        case 0x010: {
            last_instr_hb_ms = millis();
            if (can_fault) {
                can_fault = false;
                Serial.println("FAULT:1:1");   // notify recovery immediately
            }
            break;
        }

        // ── Pressure channels 1–4 ────────────────────────────────────────
        case 0x100:
            if (msg.data_length_code < 8) break;
            emit_four_int16(msg, "PRESS", 1, PRESS_SCALE, PRESS_OFFSET);
            break;

        // ── Pressure channels 5–8 ────────────────────────────────────────
        case 0x101:
            if (msg.data_length_code < 8) break;
            emit_four_int16(msg, "PRESS", 5, PRESS_SCALE, PRESS_OFFSET);
            break;

        // ── Thermocouple channels 1–4 ────────────────────────────────────
        case 0x102:
            if (msg.data_length_code < 8) break;
            emit_four_int16(msg, "TEMP", 1, TEMP_SCALE, TEMP_OFFSET);
            break;

        // ── Load cell ────────────────────────────────────────────────────
        case 0x103: {
            if (msg.data_length_code < 5) break;
            int32_t raw;
            memcpy(&raw, &msg.data[0], sizeof(int32_t));
            uint8_t lc_status = msg.data[4];
            if (lc_status != 0) {
                Serial.printf("WARNING:Load cell status = 0x%02X\r\n", lc_status);
            }
            float force = (float)raw * FORCE_SCALE + FORCE_OFFSET;
            Serial.print("SENSOR:FORCE:");
            Serial.println(force, 2);
            break;
        }

        default:
            break;   // unrecognised / our own echoed heartbeat
    }
}

/*
 * Drain the TWAI RX queue, dispatching every waiting frame. Non-blocking
 * (0-tick timeout). Draining fully each loop minimises CAN→USB latency.
 */
void poll_can() {
    twai_message_t msg;
    while (twai_receive(&msg, 0) == ESP_OK) {
        handle_can_frame(msg);
    }
}

/*
 * Send the actuation board's CAN heartbeat (ID 0x020). 8-byte LE payload:
 *   [0..3] uptime_ms u32 | [4..5] fault_flags u16 | [6] fw_major | [7] fw_minor
 *   fault_flags bit 0 = instrumentation heartbeat missing.
 */
void send_heartbeat() {
    twai_message_t hb = {};      // zero-init; standard 11-bit ID, no RTR
    hb.identifier       = 0x020;
    hb.data_length_code = 8;

    uint32_t uptime = (uint32_t)millis();
    memcpy(&hb.data[0], &uptime, 4);
    uint16_t fault_flags = can_fault ? 0x0001u : 0x0000u;
    memcpy(&hb.data[4], &fault_flags, 2);
    hb.data[6] = FW_VERSION_MAJOR;
    hb.data[7] = FW_VERSION_MINOR;

    esp_err_t err = twai_transmit(&hb, pdMS_TO_TICKS(10));
    if (err != ESP_OK && err != ESP_ERR_TIMEOUT) {
        Serial.printf("WARNING:CAN TX error %d\r\n", err);
    }
}

/*
 * [S3] CAN controller-state service. ESP-IDF TWAI does NOT auto-recover from
 * bus-off (the previous comment was wrong). On bus-off we must explicitly
 * initiate recovery; recovery ends in the STOPPED state, from which we must
 * call twai_start() again. Checked here on the 200 ms cadence.
 */
void service_can_state() {
    twai_status_info_t status;
    if (twai_get_status_info(&status) != ESP_OK) return;

    if (status.state == TWAI_STATE_BUS_OFF) {
        Serial.println("WARNING:CAN bus-off — initiating recovery");
        twai_initiate_recovery();
    } else if (status.state == TWAI_STATE_STOPPED) {
        // Reached after a recovery completes (or if never started). Restart.
        if (twai_start() == ESP_OK) {
            Serial.println("INFO:CAN restarted after recovery");
        }
    }
}

/*
 * Report CAN bus health to the GUI and run the heartbeat watchdog.
 * Emitting FAULT:1 every tick (not only on change) is deliberate: it is the
 * steady stream that keeps the GUI's link-stale watchdog from tripping.
 */
void report_can_health() {
    if (!can_fault && (millis() - last_instr_hb_ms > CAN_WATCHDOG_MS)) {
        can_fault = true;
        Serial.println("WARNING:CAN heartbeat from instrumentation board lost");
    }
    Serial.println(can_fault ? "FAULT:1:0" : "FAULT:1:1");
}


// ═══════════════════════════════════════════════════════════════
// [S1] OPERATOR-LINK WATCHDOG
// ═══════════════════════════════════════════════════════════════

/*
 * If the GUI has gone quiet for longer than GUI_LINK_TIMEOUT_MS, presume the
 * operator link is lost and fail safe. Only acts on the armed→failsafe edge.
 */
void check_link_watchdog() {
#if ENABLE_LINK_FAILSAFE
    if (!link_failsafe && (millis() - last_gui_cmd_ms > GUI_LINK_TIMEOUT_MS)) {
        enter_failsafe("linkloss");
    }
#endif
}


// ═══════════════════════════════════════════════════════════════
// COMMAND PARSER
// ═══════════════════════════════════════════════════════════════

/*
 * Parse and execute one newline-terminated ASCII command from the GUI.
 *   SRVn:500|1500|2500   move servo n (rejected while in fail-safe)
 *   STATUS               report servo positions + CAN health + arm state
 *   PING                 liveness keepalive — SILENT (no reply) by design
 *   ABORT                drive all servos safe + latch fail-safe        [S2]
 *   RESET                re-arm after abort/link-loss                   [S2]
 *   SOLn:...             rejected — no solenoid driver on this board
 * Accepted commands reply "OK"; rejected/malformed reply "ERROR:<reason>".
 */
void handle_command(String cmd) {
    cmd.trim();
    if (cmd.length() == 0) return;

    // [S1] Any line from the host proves the operator link is alive.
    last_gui_cmd_ms = millis();

    // ── PING ──────────────────────────────────────────────────────────────
    // Silent on purpose: it must not emit OK, or it would pop an unrelated
    // command off the GUI's FIFO ack queue. The timestamp update above is its
    // entire effect.
    if (cmd == "PING") {
        return;
    }

    // ── ABORT ─────────────────────────────────────────────────────────────
    if (cmd == "ABORT") {
        enter_failsafe("abort");
        Serial.println("OK");
        return;
    }

    // ── RESET (re-arm) ──────────────────────────────────────────────────────
    if (cmd == "RESET") {
        arm_system();
        Serial.println("OK");
        return;
    }

    // ── Servo commands ──────────────────────────────────────────────────────
    // Format: "SRVn:pppp" — colon always at index 4 (SRV + digit + colon).
    if (cmd.startsWith("SRV") && cmd.indexOf(':') == 4) {
        int channel = cmd.charAt(3) - '0';
        int pulse   = cmd.substring(5).toInt();

        // [S1] Refuse to move servos while latched safe.
        if (link_failsafe) {
            Serial.println("ERROR:FAILSAFE active — send RESET to re-arm before moving servos");
            return;
        }

        if (channel >= 1 && channel <= 4 &&
            (pulse == SERVO_MIN_US || pulse == SERVO_MID_US || pulse == SERVO_MAX_US)) {
            set_servo(channel, pulse);
            Serial.println("OK");
        } else {
            Serial.print("ERROR:Invalid servo command: ");
            Serial.println(cmd);
        }
    }

    // ── Solenoid commands — driver chip not present on v2 board ────────────
    else if (cmd.startsWith("SOL")) {
        Serial.println("ERROR:Solenoid driver not fitted on v2 board");
    }

    // ── Status request ──────────────────────────────────────────────────────
    else if (cmd == "STATUS") {
        Serial.print("STATUS:");
        for (int i = 1; i <= 4; i++) {
            Serial.print("SRV");
            Serial.print(i);
            Serial.print(":");
            Serial.print(servo_pulse[i]);
            if (i < 4) Serial.print(":");
        }
        Serial.print(":CAN:");
        Serial.print(can_fault ? "FAULT" : "OK");
        Serial.print(":STATE:");
        Serial.println(link_failsafe ? "FAILSAFE" : "ARMED");
        Serial.println("OK");
    }

    // ── Unknown command ─────────────────────────────────────────────────────
    else {
        Serial.print("ERROR:Unknown command: ");
        Serial.println(cmd);
    }
}


// ═══════════════════════════════════════════════════════════════
// SETUP
// ═══════════════════════════════════════════════════════════════
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
void loop() {
    unsigned long now = millis();

    // 1. Drain CAN RX queue
    poll_can();

    // 2. Process incoming serial commands
    while (Serial.available()) {
        char c = Serial.read();
        if (c == '\n') {
            handle_command(serial_buffer);
            serial_buffer = "";
        } else if (c != '\r') {
            serial_buffer += c;
            // Guard against an unterminated flood filling RAM
            if (serial_buffer.length() > 128) serial_buffer = "";
        }
    }

    // 3. [S1] Operator-link watchdog
    check_link_watchdog();

    // 4. Periodic CAN health report + [S3] bus-off service (every 200 ms)
    if (now - last_can_health_report_ms >= CAN_HEALTH_REPORT_MS) {
        last_can_health_report_ms = now;
        service_can_state();
        report_can_health();
    }

    // 5. Periodic CAN heartbeat send + arm-state echo (every 1000 ms)
    if (now - last_heartbeat_send_ms >= HEARTBEAT_SEND_MS) {
        last_heartbeat_send_ms = now;
        send_heartbeat();
        emit_state();   // 1 Hz STATE so a mid-stream GUI learns arm state
    }

    // 6. [S5] Feed the task watchdog (only reached if the loop is healthy)
#if ENABLE_TASK_WDT
    esp_task_wdt_reset();
#endif
}

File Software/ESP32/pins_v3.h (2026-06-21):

/*
 * pins_v3.h — GPIO pin assignments for the CUSF Actuation Board v2
 *
 * Hardware redesign summary vs v1:
 *   - Servos moved to GPIO 4–7 (J1–J4 signal headers)
 *   - MPQ6610 solenoid drivers removed from this board entirely;
 *     GPIO 9–14 are routed to the J6 expansion header for a future
 *     solenoid daughterboard (do not drive these for now)
 *   - All sensor reading moved to the instrumentation board;
 *     communication is now via CAN bus (SN65HVD230) on GPIO 15/16
 *     instead of the old I2C/SPI/HX711 wiring
 *
 * Pins to avoid on ESP32-S3:
 *   GPIO 0, 3, 45, 46  — strapping pins (affect boot mode)
 *   GPIO 26–32          — internal SPI flash
 *   GPIO 19, 20         — native USB (used automatically by Serial)
 *
 * CAN protocol summary (500 kbps, little-endian, 11-bit standard IDs):
 *   0x010  instr → act   Heartbeat (uptime u32 | fault_flags u16 | fw u8 u8)
 *   0x020  act → instr   Heartbeat (same layout)
 *   0x100  instr → act   Pressure ch 1–4  (4× int16 raw counts)
 *   0x101  instr → act   Pressure ch 5–8  (4× int16 raw counts)
 *   0x102  instr → act   Thermocouples 1–4 (4× int16, MAX31856 format)
 *   0x103  instr → act   Load cell (int32 reading | status u8 | 3 reserved)
 *   0x200  act → instr   Arm request    (reserved, not used yet)
 *   0x201  act → instr   Emergency stop (reserved, not used yet)
 */

#ifndef PINS_V3_H
#define PINS_V3_H

// ─── Servos (FT5330M, 7.4 V) ────────────────────────────────────────────────
// Four servo channels on J1–J4 signal headers.
// These occupy GPIO 4–7 in v2 (moved from 10–13 in v1).
#define PIN_SERVO1        4    // J1 — LEDC channel 0
#define PIN_SERVO2        5    // J2 — LEDC channel 1
#define PIN_SERVO3        6    // J3 — LEDC channel 2
#define PIN_SERVO4        7    // J4 — LEDC channel 3

// ─── Servo PWM settings ──────────────────────────────────────────────────────
// FT5330M spec: 50 Hz carrier, 500–2500 µs pulse range, 180° rotation.
// 14-bit resolution gives 16384 steps across the 20 ms period, so each
// microsecond corresponds to ~0.82 LEDC counts — more than enough precision.
#define SERVO_FREQ_HZ      50
#define SERVO_RESOLUTION   14   // 14-bit → 16384 steps per 20 ms period
#define SERVO_MIN_US       500  // fully closed
#define SERVO_MID_US       1500 // centre
#define SERVO_MAX_US       2500 // fully open

// ─── Solenoid expansion header J6 (FUTURE — do not drive) ───────────────────
// GPIO 9–14 are connected to J6 for a future MPQ6610 solenoid daughterboard.
// Initialise to a safe state (output pins low, nFAULT pins as inputs) and
// leave them alone. Do NOT connect external signals to these pins without a
// daughterboard installed — the ESP32 actively holds EN and IN low.
#define PIN_SOL_EXP1_EN      9   // MPQ6610 #1 enable  (future output)
#define PIN_SOL_EXP1_IN     10   // MPQ6610 #1 input   (future output)
#define PIN_SOL_EXP1_NFAULT 11   // MPQ6610 #1 nFAULT  (future input, active-low)
#define PIN_SOL_EXP2_EN     12   // MPQ6610 #2 enable  (future output)
#define PIN_SOL_EXP2_IN     13   // MPQ6610 #2 input   (future output)
#define PIN_SOL_EXP2_NFAULT 14   // MPQ6610 #2 nFAULT  (future input, active-low)

// ─── CAN bus (SN65HVD230 transceiver) ───────────────────────────────────────
// The ESP32 TWAI peripheral produces single-ended TX/RX logic signals.
// The SN65HVD230 converts these to the differential CAN_H / CAN_L bus.
//   TX (ESP32 GPIO 15) → SN65HVD230 pin 1 (D — driver input)
//   RX (ESP32 GPIO 16) ← SN65HVD230 pin 4 (R — receiver output)
#define PIN_CAN_RX         15
#define PIN_CAN_TX         16

#endif // PINS_V3_H

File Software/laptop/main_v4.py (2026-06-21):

"""
main_v3.py — CUSF Static Fire Test Stand Ground Station GUI.  (v3.1)

Run with:  python main_v3.py            (real hardware — DEFAULT)
           python main_v3.py --mock     (fake telemetry for UI testing only)

Layout:
    Top bar:        Port + Connect/Disconnect + link/arm status + Re-arm + ABORT
    Left column:    Solenoid controls (inert on v2) + Servo controls
    Right column:   Sensor display + Log panel

v3.1 changes (see CODE_OVERVIEW.md):
    - Mock telemetry is now OFF by default and only enabled with --mock.
      (Previously it ran on every launch, overlaying FAKE data on a real test.)
    - Timing uses a monotonic clock so an NTP/clock step cannot corrupt the
      ack/stale watchdogs mid-test.
    - The GUI sends PING ~2 Hz so the firmware's operator-link fail-safe knows
      the GUI is alive even when the operator is not clicking. If this GUI
      stops (crash / freeze / cable pull) the firmware fails the stand safe.
    - ABORT sends a single atomic ABORT command (firmware drives all servos
      safe and latches). A latched board rejects servo moves until Re-arm.
    - Re-arm button sends RESET; an ARM-state indicator reflects the firmware's
      STATE:ARMED / STATE:FAILSAFE messages.

    DEPLOY TOGETHER: the v3.1 firmware requires this v3.1 GUI (it expects the
    PING keepalive). Do not mix a v3.1 firmware with an older GUI.
"""
import os
import csv
import time
import datetime
import customtkinter as ctk

from serial_comms_v3 import find_ports, SerialConnection
from protocol_v4 import (
    Command,
    SolenoidCommand, ServoCommand, StatusCommand,
    PingCommand, AbortCommand, ResetCommand,
    Message, FaultMessage, SensorMessage, AckMessage, ErrorMessage,
    StatusMessage, StateMessage, UnknownMessage,
)


# ─── Appearance ──────────────────────────────────────────────────────────────
ctk.set_appearance_mode("dark")
ctk.set_default_color_theme("blue")


# ─── Tunables ────────────────────────────────────────────────────────────────
LINK_STALE_TIMEOUT_MS = 1500     # No msg for this long → "STALE"
LINK_CHECK_INTERVAL_MS = 200     # Watchdog tick rate
ACK_TIMEOUT_MS = 500             # Pending command must ack within this
ACK_CHECK_INTERVAL_MS = 100      # Pending-command sweeper rate
PING_INTERVAL_MS = 500           # Keepalive to the firmware link watchdog (~2 Hz)

SERVO_LABEL = {500: "Closed", 1500: "Centre", 2500: "Open"}
SERVO_COLOURS = {
    500:  ("#8B0000", "#A52A2A"),   # red
    1500: ("#B8860B", "#DAA520"),   # gold
    2500: ("#006400", "#228B22"),   # green
}


class TestStandGUI(ctk.CTk):
    """Main application window."""

    # ═══════════════════════════════════════════════════════════════
    # CONSTRUCTION
    # ═══════════════════════════════════════════════════════════════

    def __init__(self):
        super().__init__()

        self.title("CUSF Static Fire — Ground Station")
        self.geometry("1240x820")

        # ── State ─────────────────────────────────────────────────
        self.serial: SerialConnection | None = None
        self.sol_states = {1: False, 2: False}
        self.servo_states = {1: 500, 2: 500, 3: 500, 4: 500}

        # Pending commands awaiting an ACK from the ESP32.
        self._pending: list[dict] = []
        self._next_pending_id = 0

        # Watchdog / arm state
        self._last_msg_time_ms: int | None = None
        self._link_state = "disconnected"   # disconnected | live | stale
        self._armed_state = "unknown"       # unknown | ARMED | FAILSAFE

        # ── CSV logging ───────────────────────────────────────────
        os.makedirs("logs", exist_ok=True)
        log_filename = datetime.datetime.now().strftime(
            "logs/log_%Y%m%d_%H%M%S.csv"
        )
        self._log_fh = open(log_filename, "w", newline="")
        self._log_csv = csv.writer(self._log_fh)
        self._log_csv.writerow(["timestamp_utc", "message"])
        self._log_fh.flush()

        # ── Build the GUI ─────────────────────────────────────────
        self._build_top_bar()
        self._build_main_layout()
        self._build_solenoid_controls()
        self._build_servo_controls()
        self._build_sensor_display()
        self._build_log_panel()

        # ── Hooks ─────────────────────────────────────────────────
        self.protocol("WM_DELETE_WINDOW", self._on_close)

        # Start the watchdog, ack-timeout sweeper, and link keepalive
        self.after(LINK_CHECK_INTERVAL_MS, self._link_watchdog_tick)
        self.after(ACK_CHECK_INTERVAL_MS, self._ack_watchdog_tick)
        self.after(PING_INTERVAL_MS, self._ping_tick)

    # ═══════════════════════════════════════════════════════════════
    # GUI CONSTRUCTION
    # ═══════════════════════════════════════════════════════════════

    def _build_top_bar(self):
        """Connection controls + link status + arm status + Re-arm + ABORT."""
        bar = ctk.CTkFrame(self)
        bar.pack(fill="x", padx=10, pady=(10, 5))

        ctk.CTkLabel(bar, text="Port:").pack(side="left", padx=(10, 5))

        self.port_var = ctk.StringVar()
        self.port_menu = ctk.CTkOptionMenu(
            bar, variable=self.port_var, values=[""], width=180
        )
        self.port_menu.pack(side="left", padx=5)

        ctk.CTkButton(
            bar, text="Refresh", width=80, command=self.refresh_ports
        ).pack(side="left", padx=5)

        self.connect_btn = ctk.CTkButton(
            bar, text="Connect", width=110, command=self.toggle_connection
        )
        self.connect_btn.pack(side="left", padx=5)

        self.status_label = ctk.CTkLabel(
            bar, text="● Disconnected", text_color="red", width=130
        )
        self.status_label.pack(side="left", padx=10)

        # Arm / fail-safe state reported by the firmware (STATE: messages)
        self.arm_label = ctk.CTkLabel(
            bar, text="ARM: ---", text_color="gray", width=130,
            font=("", 13, "bold"),
        )
        self.arm_label.pack(side="left", padx=10)

        # ── ABORT button — far right, large, unmissable ──
        self.abort_btn = ctk.CTkButton(
            bar, text="⏻  ABORT  ⏻", width=180, height=48,
            font=("", 18, "bold"),
            fg_color="#B00020", hover_color="#D32F2F",
            text_color="white",
            command=self.abort,
        )
        self.abort_btn.pack(side="right", padx=10, pady=4)

        # ── Re-arm — left of ABORT. Clears a latched fail-safe. ──
        self.rearm_btn = ctk.CTkButton(
            bar, text="Re-arm", width=100, height=48,
            font=("", 14, "bold"),
            fg_color="#1B5E20", hover_color="#2E7D32",
            command=self.rearm,
        )
        self.rearm_btn.pack(side="right", padx=(0, 4), pady=4)

        self.refresh_ports()

    def _build_main_layout(self):
        self.main_frame = ctk.CTkFrame(self, fg_color="transparent")
        self.main_frame.pack(fill="both", expand=True, padx=10, pady=5)
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

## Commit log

2026-03-08 Add README for CUSF Test Stand actuation board
    Added detailed documentation for the CUSF Test Stand actuation board, including overview, architecture, specifications, safety interlock, GPIO assignments, power distribution, communication protocol,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
2026-03-26 Added Actuation board PCB schematic
    [actuation_board.kicad_pcb, actuation_board.kicad_sch, servos.kicad_sch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]
2026-03-27 Documentation. GUI Demo (Doesn't fully work)
    [log_20260327_230201.csv]
2026-05-10 version1 of esp32 code
    [log_20260510_091933.csv]
2026-05-17 Updated PCB
    [CAN_Bus.kicad_sch, Servos.kicad_sch, actuation_board2.kicad_sch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]
2026-05-17 updated software
    [log_20260518_005815.csv]
2026-05-24 Add initial load cell schematic design
    [Analogue_Signal.kicad_sch, CUSF_Load_Cell.kicad_pcb, CUSF_Load_Cell.kicad_sch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]
2026-05-24 Moved load cell files to new folder
    [Analogue_Signal.kicad_sch, CUSF_Load_Cell.kicad_pcb, CUSF_Load_Cell.kicad_sch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]
2026-06-21 Final schematic
    [CAN_Bus.kicad_sch, Servos.kicad_sch, actuation_board2.kicad_sch]
2026-06-21 fixed import error in software
    [log_20260518_005815.csv]
2026-06-27 Finished schematic and PCB
    [CAN_Bus.kicad_sch, Servos.kicad_sch, actuation_board2.kicad_pcb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]
2026-10-18 Bill of Materials for actuation board
2026-10-18 sensors board v2
2026-10-18 Updated BoM to include motors
2026-10-31 Updated PCB for actuation board
2026-10-31 Declutter the hardware/PCB folder
2026-11-01 test stand sensors + loadcell
2026-11-01 Updated PCB. Removed C4 capacitor and changed C5 to a through hole capacitor. Updated BoM
